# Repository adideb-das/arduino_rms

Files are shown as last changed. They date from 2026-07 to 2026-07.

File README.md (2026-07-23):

# arduino_rms

An Arduino sound level meter. It samples an electret microphone module at 8 kHz,
computes a running RMS, and shows the level on a 10-segment LED bar graph driven
by two cascaded 74HC595 shift registers. A browser page built on the Web Serial
API displays the same data live and lets you change the sensitivity without
opening the Arduino IDE.

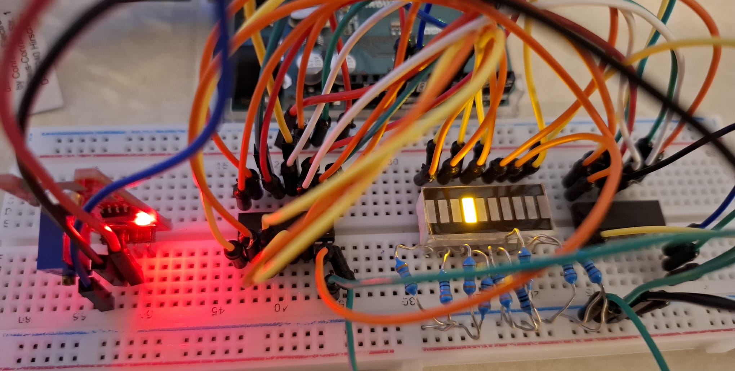
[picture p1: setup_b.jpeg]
Assembled meter: Arduino Uno, KY-038 microphone module, two 74HC595s and a ten-segment bar graph on breadboard


## What it does

The meter computes true RMS rather than peak or envelope amplitude. It keeps a
128-sample sliding window, which is 16 ms at 8 kHz, and updates the sum of
squares incrementally, so each new sample costs the same no matter how long the
window is.

The microphone module sits on a bias of roughly 2.5 V. A first-order IIR high
pass tracks that bias and subtracts it, so the circuit needs no coupling
capacitor and corrects itself when the supply drifts.

One LED floats above the solid bar at the recent maximum. It holds there for 2
seconds, then falls at 4 segments per second.

Sensitivity changes at runtime over the serial link, so you can adapt to a
different room without reflashing.

Every 250 ms the firmware prints the raw peak-to-peak swing and the current DC
estimate, then tags the line `[MIC DEAD? A0 flat]`, `[quiet]` or
`[signal alive]`. When the display stays dark, that tag tells you whether the
microphone has failed or the room is just quiet.

## Hardware

| Part | Notes |
|---|---|
| Arduino Uno (ATmega328P, 16 MHz) | Any 5 V AVR board with an ADC works |
| KY-038 sound sensor module | Analog output only. The digital threshold pin is unused |
| 2 x 74HC595 | Cascaded, 16 outputs, 10 of them used |
| 10-segment LED bar graph | |
| 10 current-limiting resistors | 220 to 470 ohm, depending on how bright you want it |

### Pin map

| Signal | Arduino pin | 74HC595 pin |
|---|---|---|
| Audio in | A0 | |
| DATA (SER) | D11 | 14 |
| CLOCK (SRCLK) | D13 | 11 |
| LATCH (RCLK) | D10 | 12 |

D13 also drives the onboard LED on the Uno, so it flickers along with the shift
register clock. That is expected and harmless.

The schematic is in `circuit_diagram.png`. The KiCad project is under
`kicad_arduino_rms/circuit_diagram_arduino_rms/`.

## Repository layout

```
codes/
  firmware/firmware.ino          Main meter firmware
  rms-meter-monitor.html         Web Serial browser monitor
  backup/                        Duplicate of the above. See Known issues
    ky-038_calibration/          Standalone microphone diagnostic sketch
    led_bar/                     Standalone shift register and LED bar test
docs/
  setup.jpg                      Photo of the assembled hardware
  gui.png                        Screenshot of the browser monitor
kicad_arduino_rms/               KiCad schematic project
presentation/                    Project presentation slides
circuit_diagram.png              Rendered schematic
footer.png                       Slide asset used by the presentation
manual.docx                      User manual
contribution_statement.docx      Author contribution statement
```

## Getting started

### 1. Check the hardware first

Bring the two halves up separately before you run the meter. A dark display is
much harder to debug when either half might be at fault.

`codes/backup/led_bar/led_bar.ino` lights the segments 0 to 10 in sequence. If
any segment stays off, the problem is in the shift registers or the bar graph
wiring.

`codes/backup/ky-038_calibration/ky-038_calibration.ino` stays silent for 3
seconds to measure the noise floor, then prints min, max, mean and peak-to-peak
continuously at 115200 baud. A quiet room gives a peak-to-peak in the single
digits and a mean near 512. Clap and it should jump well past 100. If nothing
moves, the fault is in the microphone or its wiring, not the firmware.

### 2. Flash the meter

Upload `codes/firmware/firmware.ino` and open the Serial Monitor at 115200 baud.

### 3. Set the sensitivity

Send `+` for more sensitivity and `-` for less. The default is 120, clamped
between 10 and 1000, in steps of 10.

Inside the firmware, `sensitivity` is a divisor: `level = rms * 10 / sensitivity`.
A smaller number therefore gives a more sensitive meter, and `+` decreases it.
The serial interface hides the inversion, but the variable name reads backwards
from its arithmetic and will confuse anyone reading the source.

### 4. Browser monitor

Open `codes/rms-meter-monitor.html` in Chrome or Edge. Web Serial does not work
in Firefox or Safari. Close the Arduino Serial Monitor first so the port is
free, click Connect, and pick the board. The page parses the debug lines with
tolerant regular expressions and shows RMS, LED count, peak, DC estimate and raw
peak-to-peak. Two buttons send `+` and `-`.

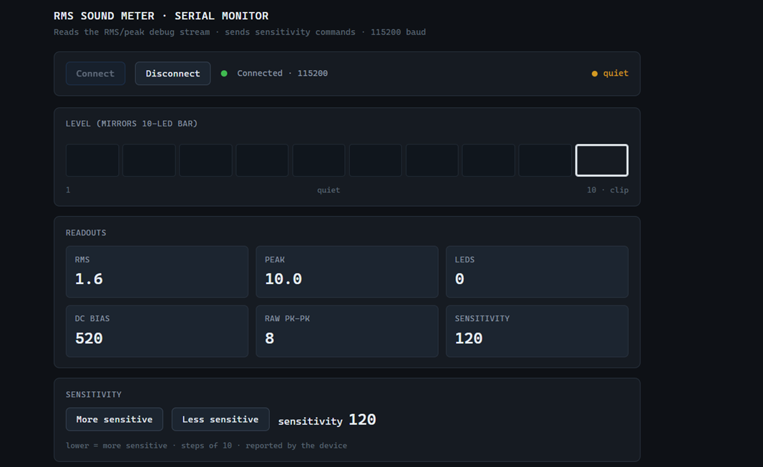
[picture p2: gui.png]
Browser monitor showing live RMS, LED count, peak, DC estimate and signal health


## How it works

### Sampling

`loop()` compares `micros()` against `nextSampleAt` and takes one `analogRead()`
every 125 us. The deadline advances by exactly one period instead of being reset
from the current time, so timing error does not accumulate. If the loop falls
more than four periods behind, which happens whenever a debug line goes out, the
schedule resets to the present. Samples are dropped on purpose, because a burst
of catch-up reads would corrupt the RMS window.

### ADC clock

`ADCSRA` is set to a /32 prescaler, which gives a 500 kHz ADC clock and about 26
us per conversion. The default /128 prescaler runs at 125 kHz and needs roughly
104 us, leaving too little room inside a 125 us budget. Atmel specifies 50 to
200 kHz for full 10-bit accuracy, so the lowest bits are noisier than the
datasheet promises. The bar graph resolves ten steps, so that extra noise does
not limit anything you can see.

### RMS

A circular buffer of 128 `int16_t` holds the samples after DC removal. Each new
sample subtracts the outgoing square from `sumSquares` and adds the incoming
one, so nothing ever loops over the window. The length is a power of two, which
lets the index wrap with a mask instead of a modulo. Worst case `sumSquares`
reaches about 128 x 512^2, or 3.4e7, well inside a `uint32_t`.

### Display

Every 25 ms the RMS is scaled to a level between 0 and 10, rounded to a segment
count, turned into a bit pattern, and shifted out MSB first as two bytes. The
peak marker is OR-ed in only when it sits strictly above the solid bar. Peak
decay is computed from elapsed milliseconds rather than per frame, so jitter in
the display loop does not change the fall rate.

## Design parameters

| Constant | Value | Meaning |
|---|---|---|
| `SAMPLE_RATE_HZ` | 8000 | 4 kHz usable bandwidth |
| `BUF_LEN` | 128 | 16 ms RMS window. Must stay a power of two |
| `DISPLAY_PERIOD_MS` | 25 | 40 Hz refresh |
| `PEAK_HOLD_MS` | 2000 | Marker freeze before decay |
| `PEAK_DECAY_PER_SEC` | 4.0 | Segments per second |
| `sensitivity` | 120 | Divisor. Lower means more sensitive |
| `SERIAL_DEBUG` | true | Set false to remove all serial output |

## Limitations

The output is not calibrated in dB SPL. It is a relative RMS in ADC counts with
no weighting curve. Real decibels would need a reference sound source and a
known microphone sensitivity, and without A-weighting the response does not
follow how people actually hear loudness.

Usable bandwidth stops at 4 kHz. Anything above that folds back into the
measurement band, and the KY-038 has no anti-aliasing filter.

Serial debug output disturbs the sampling. A debug line at 115200 baud takes
several milliseconds to send and blocks once the 64-byte transmit buffer fills,
so a few samples vanish every 250 ms. Set `SERIAL_DEBUG` to false for the
cleanest measurement.

`shiftOut()` bit-bangs 16 bits with `digitalWrite()`, which is slow on an AVR,
and the call very likely overruns a single 125 us sample slot. It only fires
every 25 ms, so the duty is low and the sampler resyncs afterwards, but the cost
has not been measured. Hardware SPI would remove the question entirely.

## Coursework context

Built for the Complex Embedded Systems lab, MSc Micro- and Nanotechnology,
Technische Universität Ilmenau.Operating instructions are in `manual.docx`.

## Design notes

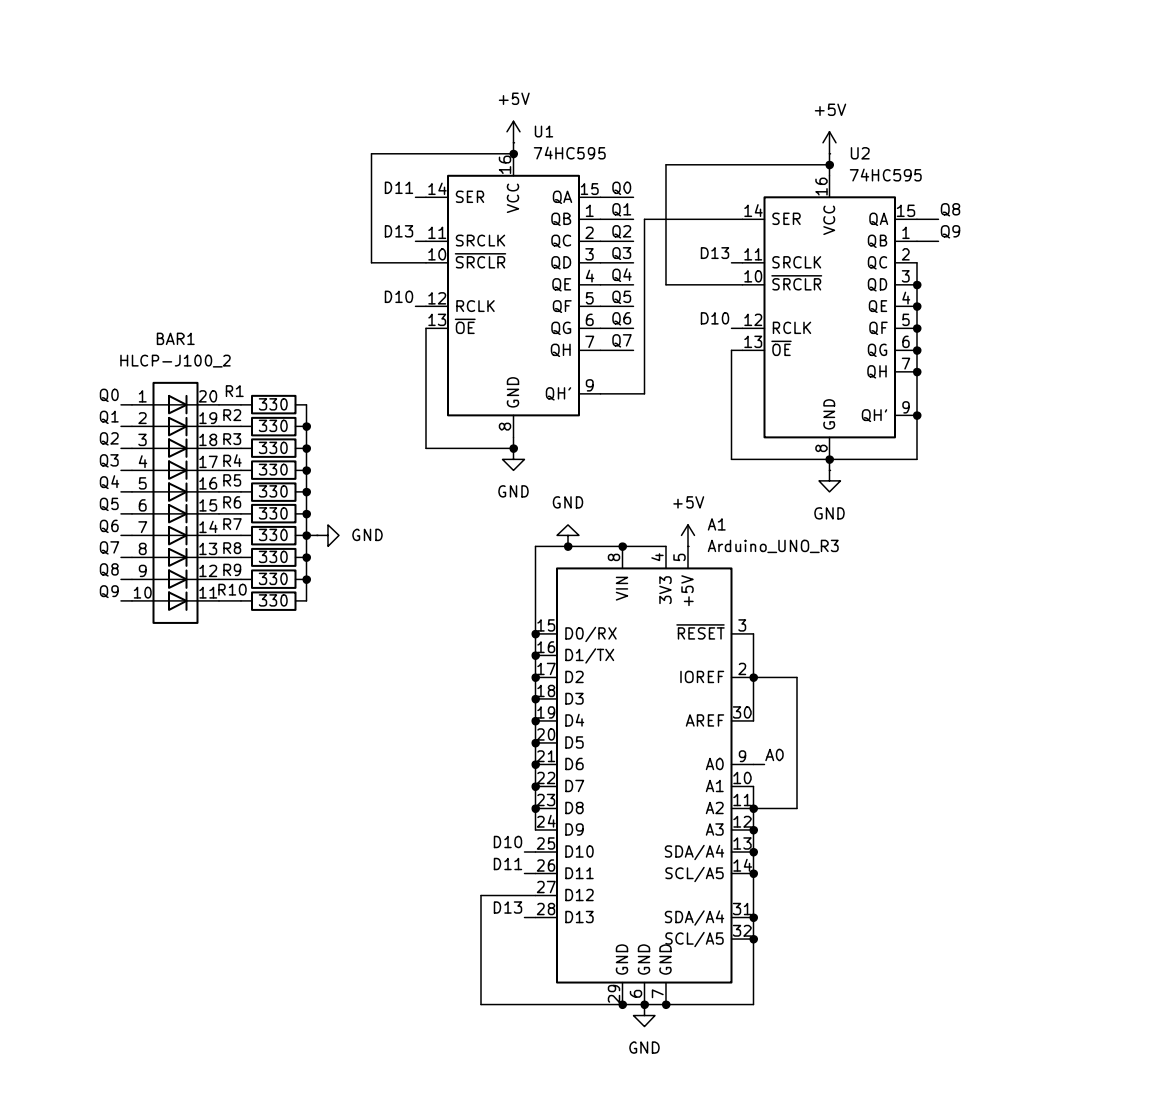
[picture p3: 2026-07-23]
circuit_diagram.png

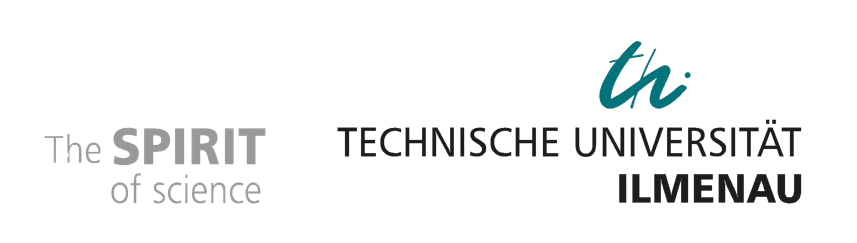
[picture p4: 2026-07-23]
footer.png

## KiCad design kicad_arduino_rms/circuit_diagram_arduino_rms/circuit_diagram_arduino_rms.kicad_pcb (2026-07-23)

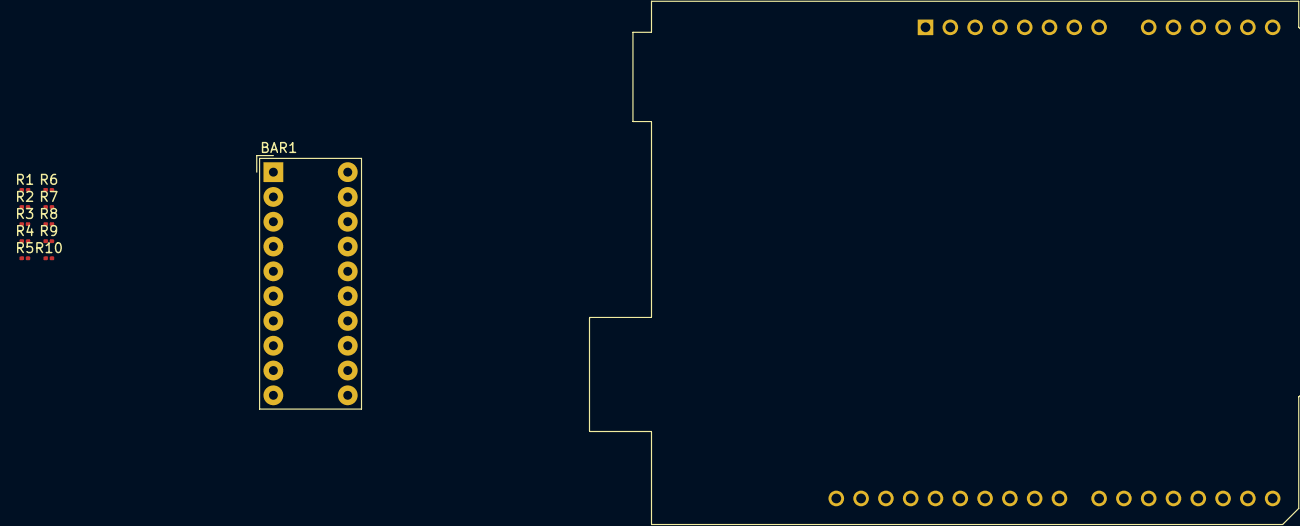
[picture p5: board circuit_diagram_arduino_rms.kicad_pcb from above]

Board: 2 copper layers, 12 parts (0 on the bottom side), 11 nets, no tracks yet.

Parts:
A1: Arduino_UNO_R3
BAR1: HLCP-J100_2; HLCP-J100
R1, R2, R3, R4, R5, R6, R7, R8, R9, R10: 330; R_0201_0603Metric

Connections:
GND: A1.2 (IOREF), A1.3 (~RESET), A1.4 (3V3), A1.6 (GND), A1.7 (GND), A1.8 (VIN), A1.10 (A1), A1.11 (A2), A1.12 (A3), A1.13 (SDA/A4), A1.14 (SCL/A5), A1.15 (D0/RX), A1.16 (D1/TX), A1.17 (D2), A1.18 (D3), A1.19 (D4), A1.20 (D5), A1.21 (D6), A1.22 (D7), A1.23 (D8), A1.24 (D9), A1.27 (D12), A1.29 (GND), A1.30 (AREF), A1.31 (SDA/A4), A1.32 (SCL/A5), R1.2, R2.2, R3.2, R4.2, R5.2, R6.2, R7.2, R8.2, R9.2, R10.2
unnamed: BAR1.11 (K), R10.1
unnamed: BAR1.12 (K), R9.1
unnamed: BAR1.13 (K), R8.1
unnamed: BAR1.14 (K), R7.1
unnamed: BAR1.15 (K), R6.1
unnamed: BAR1.16 (K), R5.1
unnamed: BAR1.17 (K), R4.1
unnamed: BAR1.18 (K), R3.1
unnamed: BAR1.19 (K), R2.1
unnamed: BAR1.20 (K), R1.1

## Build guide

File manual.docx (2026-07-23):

User Manual

Audio RMS Display: an Arduino sound-level meter with a 10-segment LED bar and a browser monitor

1. Overview

The file firmware.ino contains the complete program and is already flashed to the Arduino. The meter works on its own: plug in power and the LED bar shows the ambient sound level. The browser monitor is optional. It adds numeric readouts and lets you change the sensitivity.

2. Getting started

1. Connect the Arduino to the computer with a USB cable. The LED bar starts working right away.
2. Open rms-meter-monitor.html in Google Chrome or Microsoft Edge. Firefox and Safari do not support the Web Serial interface, so the Connect button will not work there.
3. Click Connect, pick the Arduino from the port list, and confirm. The status changes to “Connected · 115200” and live values appear within about a second.

Note: connecting resets the board, so the sensitivity goes back to its default of 120. The monitor picks up the correct values automatically from the incoming data.

3. Operation

- Clap, speak, shout, or play music. The bar rises with the loudness of the sound (the RMS level). More lit LEDs means a louder signal.
- A single marker LED above the bar shows the recent peak. It holds for two seconds and then falls back slowly.
- The monitor mirrors the physical bar and shows the RMS, peak, DC bias, raw peak-to-peak, and the current sensitivity.

4. Adjusting the sensitivity

Use More sensitive / Less sensitive in the monitor, or send '+' or '-' from any serial terminal at 115200 baud. If the bar sits at full scale all the time, click Less sensitive. If it barely reacts, click More sensitive. The monitor shows the current value, and the device confirms every change.

5. Health indicator

- signal alive: the microphone delivers a normal signal.
- quiet: very little signal. The room is silent or the microphone gain is set too low.
- mic dead? A0 flat: the input does not move at all. Check the KY-038 wiring and its power supply.

6. Folder contents

The submission folder contains everything needed to review the project and to debug it:

- Presentation: the final slide deck.
- Circuit diagram: KiCad source files for the full schematic.
- Contribution statement: a one-page summary of each student's work.
- Codes: all source files for the project.
  - firmware/ firmware.ino, the complete program that runs on the Arduino.
  - backup/ holds two development sketches: a KY-038 calibration file and an LED bar graph test.
  - rms-meter-monitor.html is the browser serial monitor. It mirrors the physical LED bar and shows the live readings over Web Serial.

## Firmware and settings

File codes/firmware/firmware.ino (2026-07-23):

//test 2

#include <Arduino.h>
//Assigned Pins
const uint8_t PIN_AUDIO = A0;   // KY-038 analog output
const uint8_t PIN_DATA  = 11;   // 74HC595 SER  (pin 14)
const uint8_t PIN_CLK   = 13;   // 74HC595 SCLK (pin 11)
const uint8_t PIN_LATCH = 10;   // 74HC595 RCLK (pin 12)

//Sampling
const uint16_t SAMPLE_RATE_HZ   = 8000;
const uint16_t SAMPLE_PERIOD_US = 1000000UL / SAMPLE_RATE_HZ; // 125 us
const uint16_t BUF_LEN          = 128;   // 16 ms RMS window @ 8 kHz; MUST be a power of two
const uint16_t BUF_MASK         = BUF_LEN - 1;

int16_t  sampleBuf[BUF_LEN];
uint16_t bufIdx       = 0;
uint32_t sumSquares   = 0;
uint32_t nextSampleAt = 0;

int32_t dcEstimate = 512L << 8;

//Signal-health telemetry
uint16_t rawMin = 1023;
uint16_t rawMax = 0;

//Display
const uint8_t  NUM_LEDS          = 10;
const uint16_t DISPLAY_PERIOD_MS = 25;
int16_t sensitivity = 120;
uint32_t nextDisplayAt = 0;
const bool SERIAL_DEBUG = true;
uint32_t nextDebugAt = 0;

//Peak-hold state
float    peakLevel      = 0;      // 0..NUM_LEDS, fractional for smooth decay
uint32_t peakHoldUntil  = 0;
uint32_t lastPeakUpdate = 0;
const uint16_t PEAK_HOLD_MS       = 2000;  // freeze time before decay starts
const float    PEAK_DECAY_PER_SEC = 4.0;  // LED segments/sec fall rate — tune this

void writeLeds(uint16_t pattern) {
  digitalWrite(PIN_LATCH, LOW);
  shiftOut(PIN_DATA, PIN_CLK, MSBFIRST, (pattern >> 8) & 0xFF);
  shiftOut(PIN_DATA, PIN_CLK, MSBFIRST,  pattern       & 0xFF);
  digitalWrite(PIN_LATCH, HIGH);
}

void setup() {
  pinMode(PIN_DATA,  OUTPUT);
  pinMode(PIN_CLK,   OUTPUT);
  pinMode(PIN_LATCH, OUTPUT);

  ADCSRA = (ADCSRA & 0xF8) | 0x05;

  Serial.begin(115200);
  Serial.println(F("Audio RMS meter ready."));
  Serial.println(F("Send '+' for more sensitivity, '-' for less."));

  for (uint16_t i = 0; i < BUF_LEN; i++) sampleBuf[i] = 0;

  writeLeds(0);
  nextSampleAt   = micros();
  nextDisplayAt  = millis();
  lastPeakUpdate = millis();
}

void loop() {
  //User interface
  while (Serial.available()) {
    char c = Serial.read();
    if (c == '+')      sensitivity = max(10,   sensitivity - 10);
    else if (c == '-') sensitivity = min(1000, sensitivity + 10);
    if (c == '+' || c == '-') {
      Serial.print(F("sensitivity = ")); Serial.println(sensitivity);
    }
  }

  //Audio sampling at a fixed rate 
  if ((int32_t)(micros() - nextSampleAt) >= 0) {
    int32_t late = (int32_t)(micros() - nextSampleAt);
    if (late > (int32_t)(4 * SAMPLE_PERIOD_US)) nextSampleAt = micros();
    else                                        nextSampleAt += SAMPLE_PERIOD_US;

    int16_t raw = analogRead(PIN_AUDIO);          // 0..1023

    //signal-health tracking on the RAW signal
    if ((uint16_t)raw < rawMin) rawMin = raw;
    if ((uint16_t)raw > rawMax) rawMax = raw;

    dcEstimate += (((int32_t)raw << 8) - dcEstimate) >> 9;
    int16_t hp = raw - (int16_t)(dcEstimate >> 8);

    int32_t oldS = sampleBuf[bufIdx];
    sumSquares -= (uint32_t)(oldS * oldS);
    sumSquares += (uint32_t)((int32_t)hp * hp);
    sampleBuf[bufIdx] = hp;
    bufIdx = (bufIdx + 1) & BUF_MASK;
  }

  //Display update
  uint32_t now = millis();
  if ((int32_t)(now - nextDisplayAt) >= 0) {
    nextDisplayAt = now + DISPLAY_PERIOD_MS;

    float rms = sqrt((float)sumSquares / BUF_LEN);

    float level = rms * NUM_LEDS / sensitivity;
    if (level > NUM_LEDS) level = NUM_LEDS;
    if (level < 0)        level = 0;

    uint8_t  barLeds = (uint8_t)(level + 0.5);
    uint16_t pattern = 0;
    for (uint8_t i = 0; i < barLeds; i++) pattern |= (1u << i);

    //Peak-hold with gradual decay 
    uint32_t dtMs = now - lastPeakUpdate;
    lastPeakUpdate = now;

    if (level >= peakLevel) {
      peakLevel     = level;
      peakHoldUntil = now + PEAK_HOLD_MS;
    } else if ((int32_t)(now - peakHoldUntil) >= 0) {
      peakLevel -= PEAK_DECAY_PER_SEC * (dtMs / 1000.0f);
      if (peakLevel < level) peakLevel = level;  // don't let marker sink into the live bar
    }
    if (peakLevel < 0) peakLevel = 0;

    uint8_t peakLedIndex = (uint8_t)(peakLevel + 0.5);
    if (peakLedIndex > barLeds && peakLedIndex >= 1 && peakLedIndex <= NUM_LEDS) {
      pattern |= (1u << (peakLedIndex - 1));   // single marker LED above the solid bar
    }

    writeLeds(pattern);

    //Debug + signal-health output
    if (SERIAL_DEBUG && (int32_t)(now - nextDebugAt) >= 0) {
      nextDebugAt = now + 250;

      uint16_t pkpk = rawMax - rawMin;
      uint16_t dc   = (uint16_t)(dcEstimate >> 8);

      Serial.print(F("RMS: "));         Serial.print(rms, 1);
      Serial.print(F("  sensitivity: ")); Serial.print(sensitivity);
      Serial.print(F("  LEDs: "));      Serial.print(barLeds);
      Serial.print(F("  peak: "));      Serial.print(peakLevel, 1);
      Serial.print(F("  dc: "));        Serial.print(dc);
      Serial.print(F("  raw pk-pk: ")); Serial.print(pkpk);

      if (pkpk < 3)        Serial.println(F("  [MIC DEAD? A0 flat]"));
      else if (pkpk < 15)  Serial.println(F("  [quiet]"));
      else                 Serial.println(F("  [signal alive]"));

      rawMin = 1023;
      rawMax = 0;
    }
  }
}
